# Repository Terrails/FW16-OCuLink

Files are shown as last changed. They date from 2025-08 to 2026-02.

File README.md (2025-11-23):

# OCuLink 8i Expansion Board for the Framework 16

## The schematic
rev1.1

The schematic in itself is pretty simple. You only need to connect the TX and RX PCIe lanes to the correct pins of the OCuLink connector. And then add components such as the EEPROM that the Embedded Controller (EC) on the laptop reads to configure GPIO pins and bifurcation.

A pdf version of the schematic is available [here](./imgs/schematic.pdf).

### EEPROM
As for the EEPROM, I have decided to use the same one that Framework is using in their [Dual SSD reference design](https://github.com/FrameworkComputer/ExpansionBay/tree/main/Dual%20SSD%20Reference%20Design). The `BR24G32FVT-3GE2`. The chip is marked as not recommended for new design according to Mouser, but it still seems to be in stock, although it can easily be swapped with another if required.

The EEPROM's address pins are all connected to the ground as that is the address the EC expects and by default the write protection (WP) is disabled by being connected to GND to allow writing data to it.

### Fans
For the fans I had to go with an alternative FPC header, as the one Framework uses on their boards was not available anywhere. The connector I use is slightly smaller, but still makes the connection nevertheless and the fans do spin up. I have specifically went with the [`AFC05-S04FIA-00`](https://www.lcsc.com/product-detail/C561383.html) that is available on LCSC to use with JLCPCB's assembly.

## Firmware
The firmware file is generated using [Framework's Expansion Bay tool](https://github.com/FrameworkComputer/ExpansionBayConfigurationGenerator). More info on the specific file I have been using in my testing and how I flashed it *SOON*.

## The PCB layout
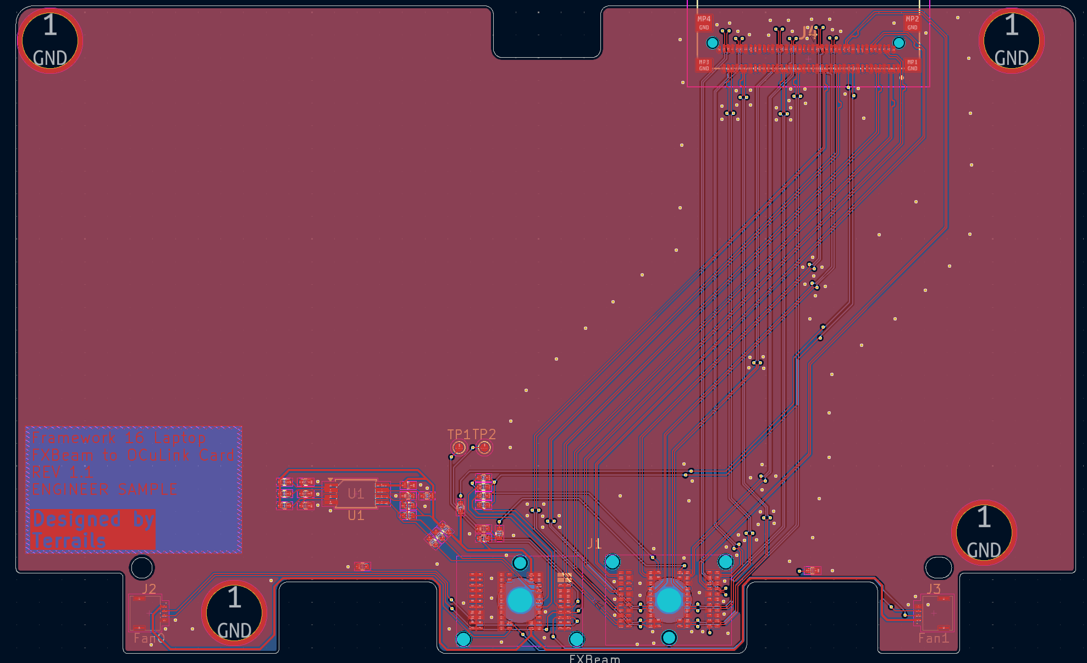
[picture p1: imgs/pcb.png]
rev1.1


For the layout I have went with a 4-layer board and did manage to successfully stay within JLCPCB's fabrication limits. For the production runs I have done a 1.2mm ENIG board and used the `Nan Ya NP-140F` material type with the `JLC04121H-1080` stackup and matched the differential pairs to it. I did also manage to stay within the minimum 0.3mm via hole size to keep costs somewhat down.

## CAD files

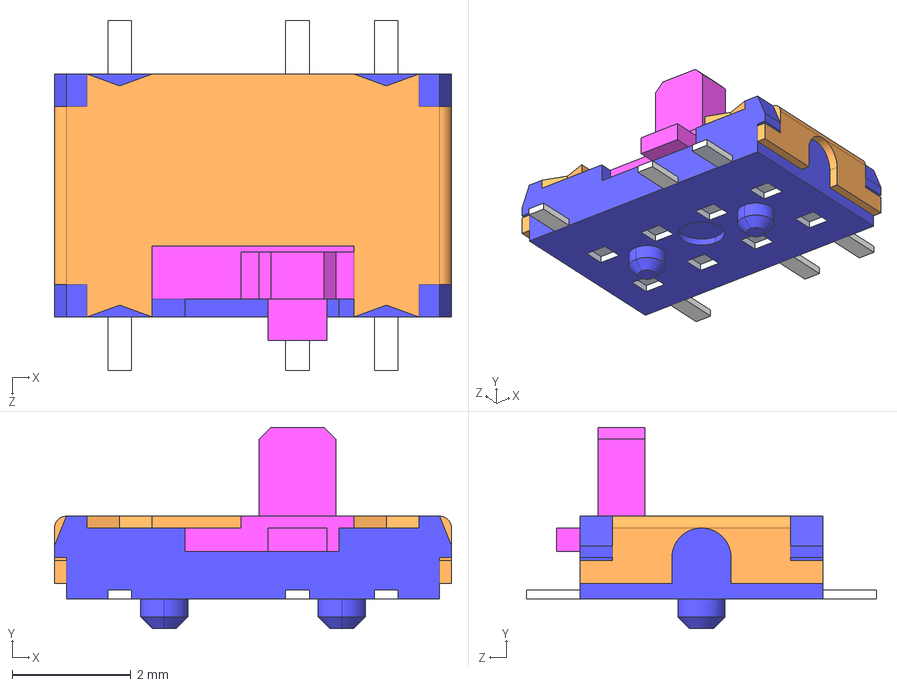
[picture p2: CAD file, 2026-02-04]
components/SSSS820101.stp
6.70 x 3.40 x 5.90 mm

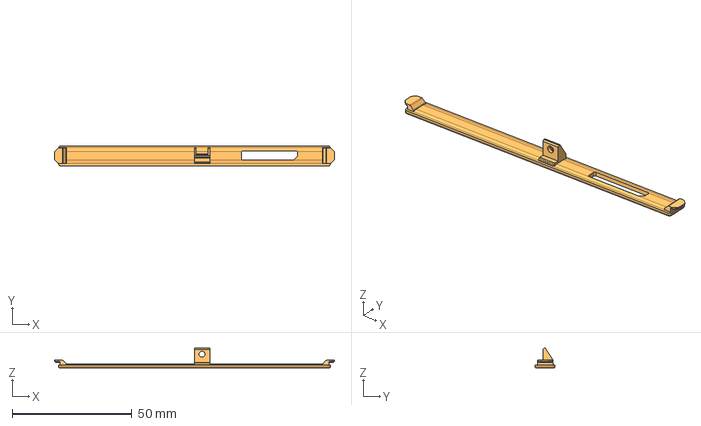
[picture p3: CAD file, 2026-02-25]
prints/IO-Shield.step
116.9 x 8.45 x 8.15 mm

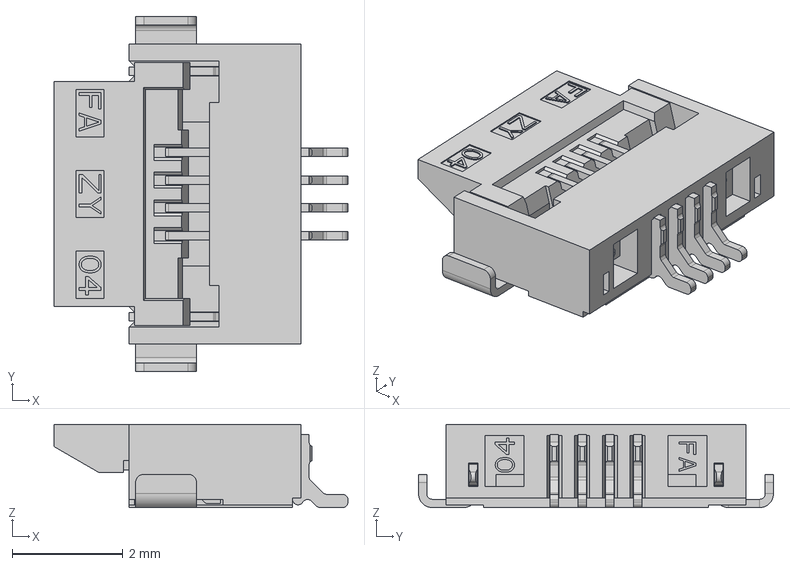
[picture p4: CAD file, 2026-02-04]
components/AFC58-S04FIA_4Pin.stp
5.30 x 6.40 x 1.50 mm

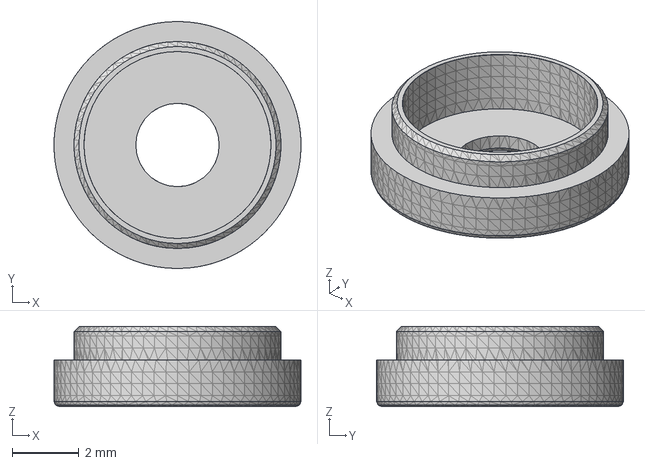
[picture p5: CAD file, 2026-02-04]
components/Expansion_Bay_Standoff.stp
7.40 x 7.40 x 2.40 mm

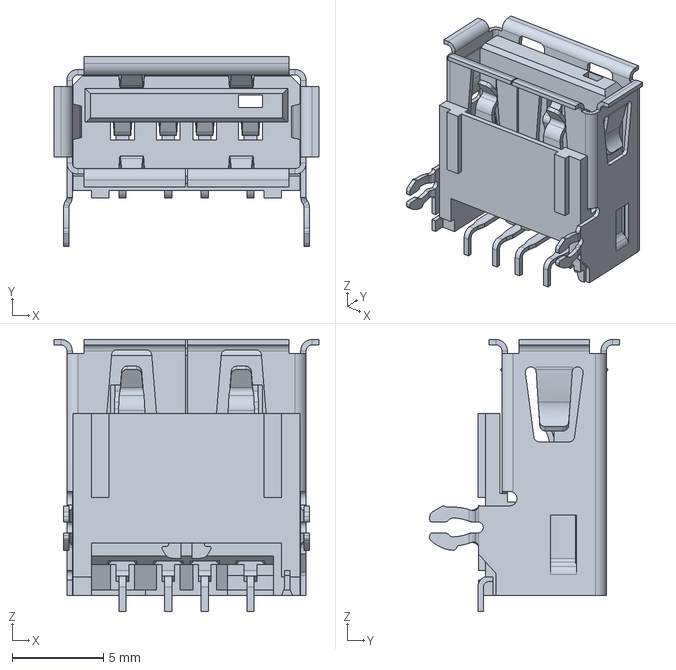
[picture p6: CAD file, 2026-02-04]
components/87583-2010BLF.stp
14.5 x 10.4 x 14.9 mm

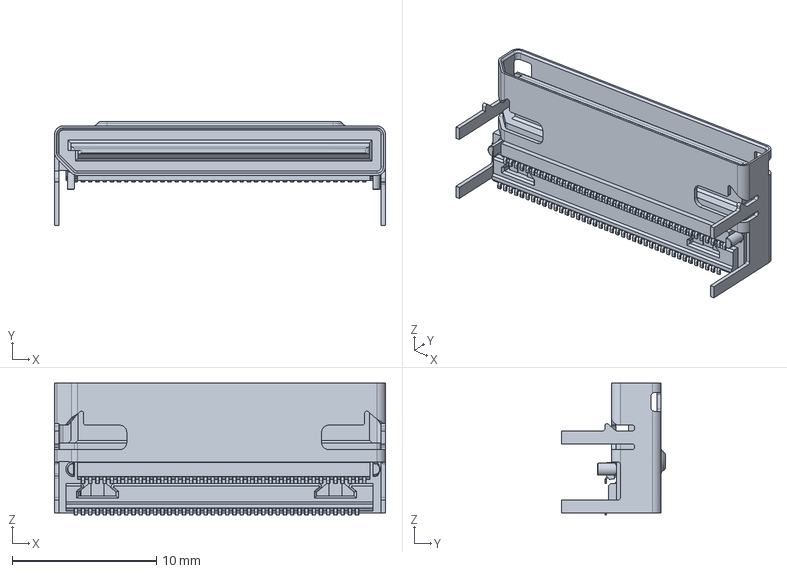
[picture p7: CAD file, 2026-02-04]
components/173162-0132.stp
22.9 x 7.21 x 9.14 mm

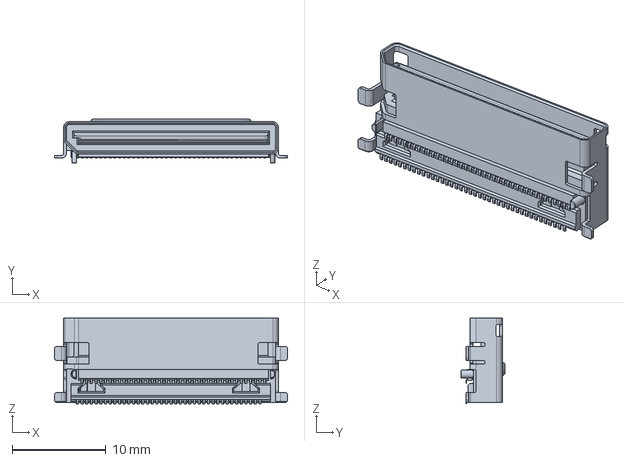
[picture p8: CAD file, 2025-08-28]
components/173162-0131.stp
24.9 x 4.72 x 9.14 mm

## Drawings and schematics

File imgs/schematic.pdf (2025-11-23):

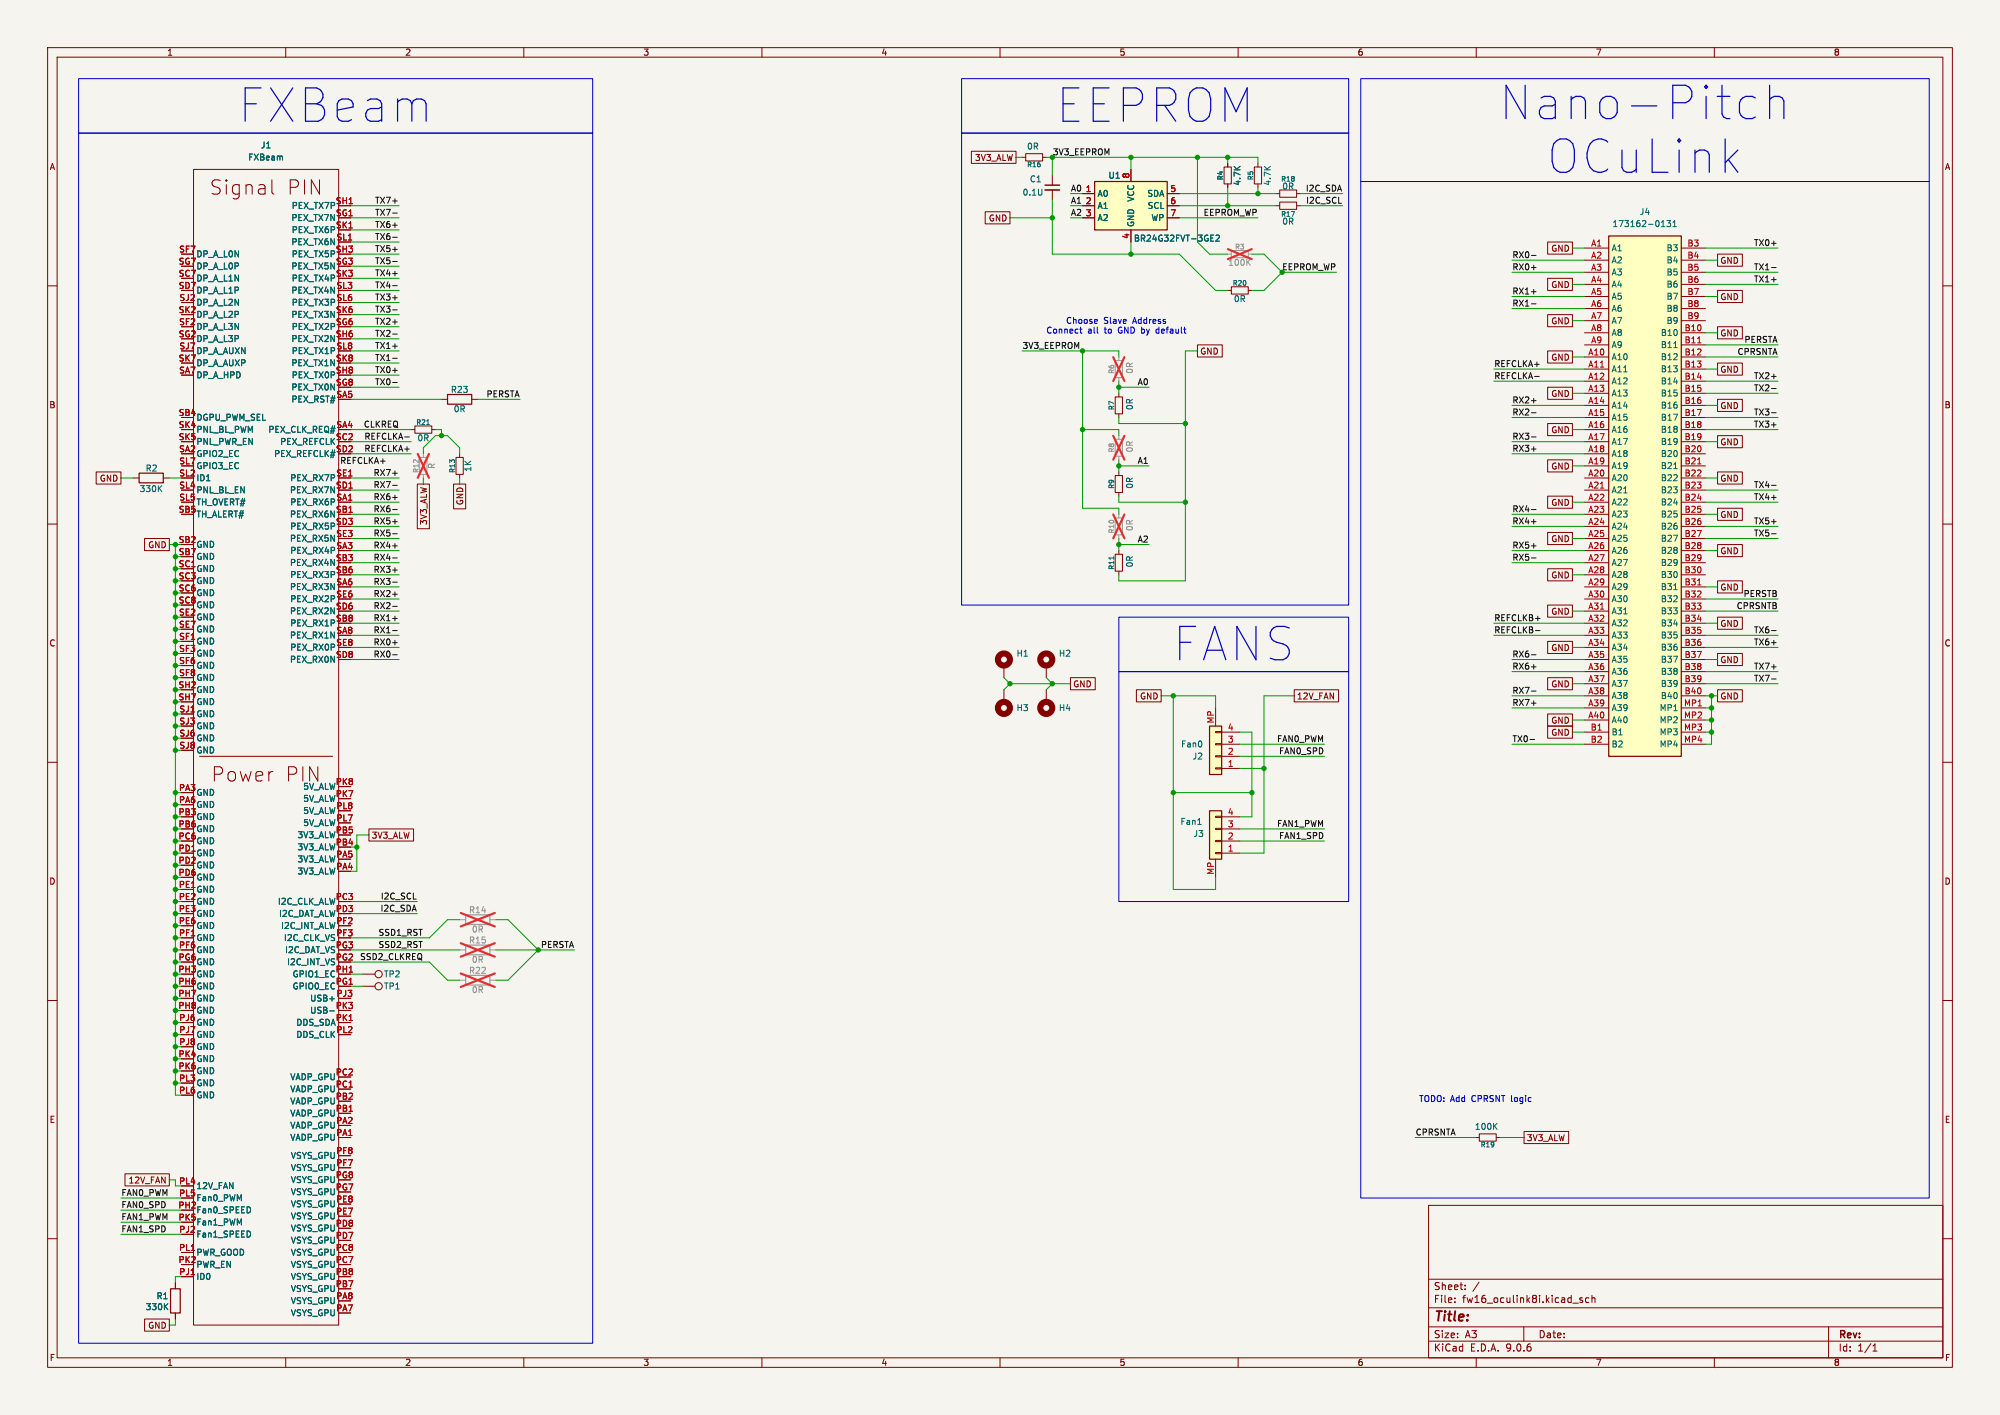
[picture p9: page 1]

Choose Slave Address Connect all to GND by default

ID1 SL2 PNL_BL_EN SL4 TH_OVERT# SL5 TH_ALERT# SB5 GND SB2 GND SB7 GND SC1 GND SC3 GND SC6 GND SC8 GND SE2 GND SE7 GND SF1 GND SF3 GND SF6 GND SF8 GND SH2 GND SH7 GND SJ1 GND SJ3 GND SJ6 GND SJ8 GND PA3 GND PA6 GND PB3 GND PB6 GND PC6 GND PD1 GND PD2 GND PD6 GND PE1 GND PE2 GND PE3 GND PE6 GND PF1 GND PF6 GND PG6GND PH3 GND PH6 GND PH7 GND PH8 GND PJ6 GND PJ7 GND PJ8 GND PK4 GND PK6 GND PL3 GND PL6

GND GND GND GND GND

Id: 1/1 Title: File: fw16_oculink8i.kicad_sch Sheet: /

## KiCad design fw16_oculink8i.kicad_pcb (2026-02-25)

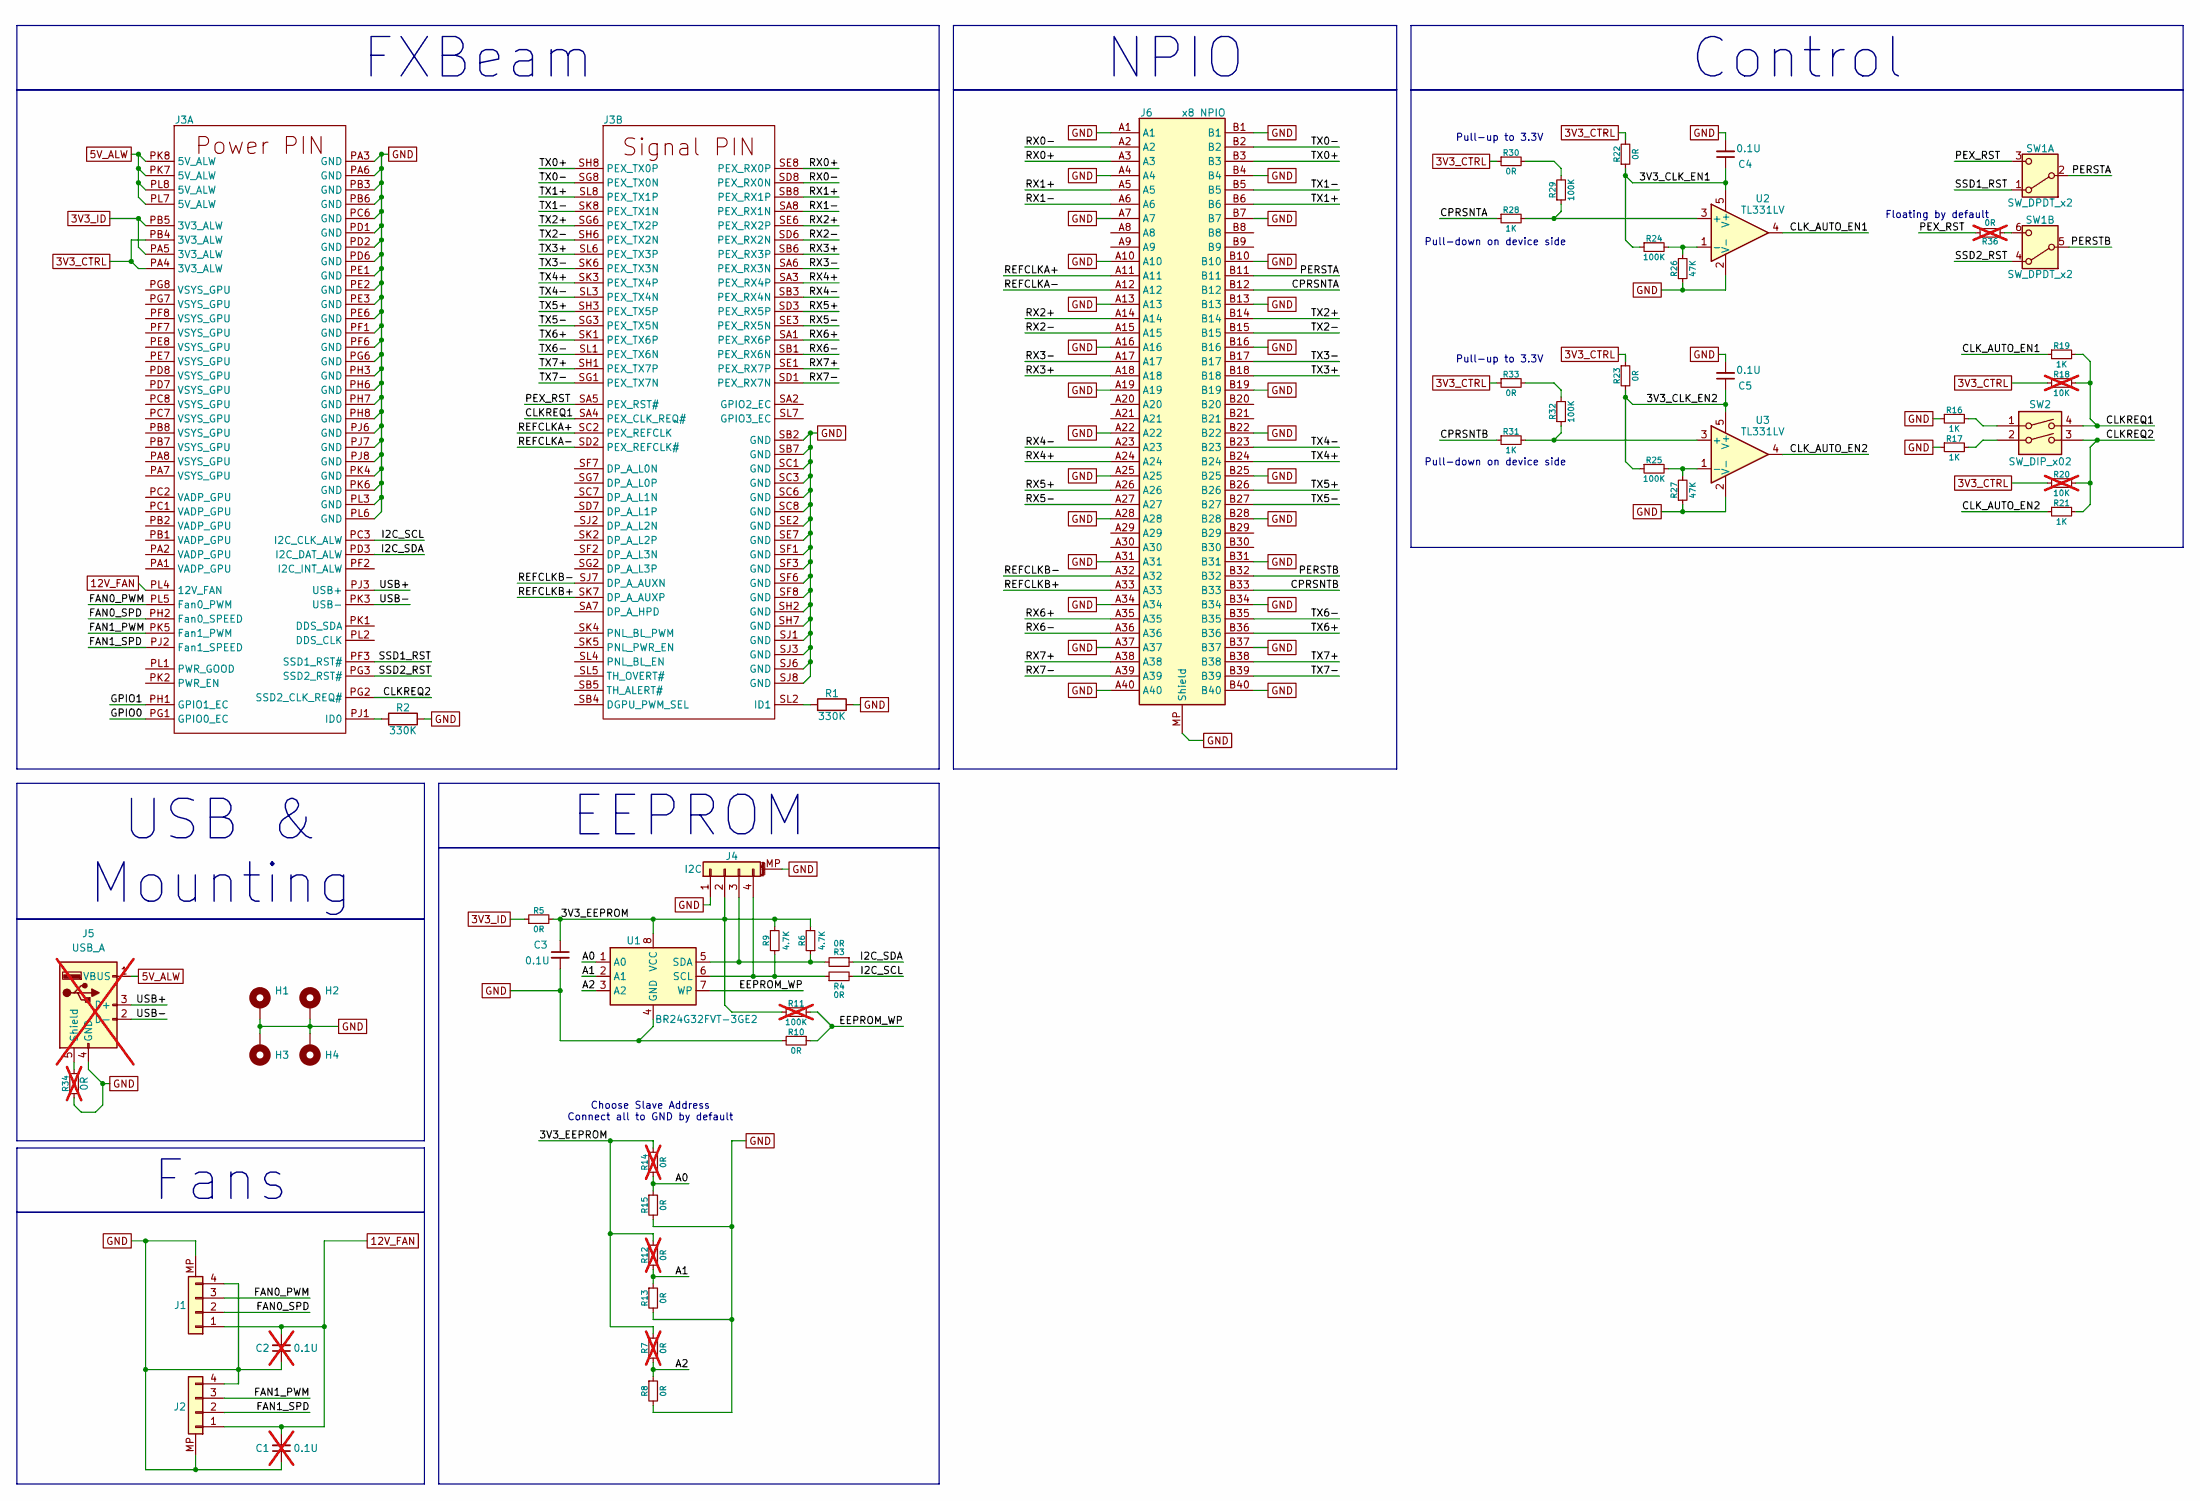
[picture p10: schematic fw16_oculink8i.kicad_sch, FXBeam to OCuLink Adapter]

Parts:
C1, C2: 0.1U; C_0402_1005Metric; not fitted
C3, C4, C5: 0.1U; C_0402_1005Metric
H1, H2, H3, H4: MountingHole_Pad; MountingHole_6.2mm_EasySolder_Cut
J1, J2: Fan; AFC58-S04FIA_4Pin; Part Nr. AFC58-S04FIA
J3: FXBeam
J4: I2C; JST_SH_SM04B-SRSS-TB_1x04-1MP_P1.00mm_Horizontal
J5: USB_A; 87583-2010BLF; not fitted
J6: x8 NPIO; Nano-Pitch-173162-0132
R1, R2: 330K; R_0402_1005Metric; Tolerance 1%
R3, R4, R5, R8, R10, R13, R15, R22, R23, R30, R33: 0R; R_0402_1005Metric
R6, R9: 4.7K; R_0402_1005Metric; Tolerance 1%
R7, R12, R14, R34, R36: 0R; R_0402_1005Metric; not fitted
R11: 100K; R_0402_1005Metric; Tolerance 1%; not fitted
R16, R17, R19, R21, R28, R31: 1K; R_0402_1005Metric
R18, R20: 10K; R_0402_1005Metric; not fitted
R24, R25, R29, R32: 100K; R_0402_1005Metric
R26, R27: 47K; R_0402_1005Metric
SW1: SW_DPDT_x2; SSSS820101
SW2: SW_DIP_x02; SW_DIP_SPSTx02_Slide_Copal_CHS-02B_W7.62mm_P1.27mm
U1: BR24G32FVT-3GE2; TSSOP-8_4.4x3mm_P0.65mm
U2, U3: TL331LV; SOT-23-5

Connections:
3V3_CTRL: J3.PA4 (3V3_ALW), J3.PB4 (3V3_ALW), R18.1, R20.1, R22.2, R23.1, R30.1, R33.1
3V3_ID: J3.PA5 (3V3_ALW), J3.PB5 (3V3_ALW), R5.1
5V_ALW: J3.PK7 (5V_ALW), J3.PK8 (5V_ALW), J3.PL7 (5V_ALW), J3.PL8 (5V_ALW), J5.1 (VBUS)
12V_FAN: C1.2, C2.2, J1.1, J2.1, J3.PL4 (12V_FAN)
/3V3_CLK_EN1: C4.1, R22.1, R24.1, U2.5 (V+)
/3V3_CLK_EN2: C5.1, R23.2, R25.1, U3.5 (V+)
/3V3_EEPROM: C3.1, J4.2, R5.2, R6.2, R7.1, R9.1, R11.2, R12.1, R14.1, U1.8 (VCC)
/A0: R14.2, R15.1, U1.1 (A0)
/A1: R12.2, R13.1, U1.2 (A1)
/A2: R7.2, R8.1, U1.3 (A2)
/CLKREQ1: J3.SA4 (PEX_CLK_REQ#), R18.2, R19.2, SW2.4
/CLKREQ2: J3.PG2 (SSD2_CLK_REQ#), R20.2, R21.2, SW2.3
/CLK_AUTO_EN1: R19.1, U2.4
/CLK_AUTO_EN2: R21.1, U3.4
/CPRSNTA: J6.B12, R28.1
/CPRSNTB: J6.B33, R31.1
/EEPROM_WP: R10.1, R11.1, U1.7 (WP)
/FAN0_PWM: J1.3, J3.PL5 (Fan0_PWM)
/FAN0_SPD: J1.2, J3.PH2 (Fan0_SPEED)
/FAN1_PWM: J2.3, J3.PK5 (Fan1_PWM)
/FAN1_SPD: J2.2, J3.PJ2 (Fan1_SPEED)
/GPIO0: J3.PG1 (GPIO0_EC)
/GPIO1: J3.PH1 (GPIO1_EC)
/I2C_SCL: J3.PC3 (I2C_CLK_ALW), R4.2
/I2C_SDA: J3.PD3 (I2C_DAT_ALW), R3.1
/PERSTA: J6.B11, SW1.2 (B)
/PERSTB: J6.B32, SW1.5 (B)
/PEX_RST: J3.SA5 (PEX_RST#), R36.2, SW1.3 (C)
/REFCLKA+: J3.SC2 (PEX_REFCLK), J6.A11
/REFCLKA-: J3.SD2 (PEX_REFCLK#), J6.A12
/REFCLKB+: J3.SK7 (DP_A_AUXP), J6.A33
/REFCLKB-: J3.SJ7 (DP_A_AUXN), J6.A32
/RX0+: J3.SE8 (PEX_RX0P), J6.A3
/RX0-: J3.SD8 (PEX_RX0N), J6.A2
/RX1+: J3.SB8 (PEX_RX1P), J6.A5
/RX1-: J3.SA8 (PEX_RX1N), J6.A6
/RX2+: J3.SE6 (PEX_RX2P), J6.A14
/RX2-: J3.SD6 (PEX_RX2N), J6.A15
/RX3+: J3.SB6 (PEX_RX3P), J6.A18
/RX3-: J3.SA6 (PEX_RX3N), J6.A17
/RX4+: J3.SA3 (PEX_RX4P), J6.A24
/RX4-: J3.SB3 (PEX_RX4N), J6.A23
/RX5+: J3.SD3 (PEX_RX5P), J6.A26
/RX5-: J3.SE3 (PEX_RX5N), J6.A27
/RX6+: J3.SA1 (PEX_RX6P), J6.A35
/RX6-: J3.SB1 (PEX_RX6N), J6.A36
/RX7+: J3.SE1 (PEX_RX7P), J6.A38
/RX7-: J3.SD1 (PEX_RX7N), J6.A39
/SSD1_RST: J3.PF3 (SSD1_RST#), SW1.1 (A)
/SSD2_RST: J3.PG3 (SSD2_RST#), SW1.4 (A)
/TX0+: J3.SH8 (PEX_TX0P), J6.B3
/TX0-: J3.SG8 (PEX_TX0N), J6.B2
/TX1+: J3.SL8 (PEX_TX1P), J6.B6
/TX1-: J3.SK8 (PEX_TX1N), J6.B5
/TX2+: J3.SG6 (PEX_TX2P), J6.B14
/TX2-: J3.SH6 (PEX_TX2N), J6.B15
/TX3+: J3.SL6 (PEX_TX3P), J6.B18
/TX3-: J3.SK6 (PEX_TX3N), J6.B17
/TX4+: J3.SK3 (PEX_TX4P), J6.B24
/TX4-: J3.SL3 (PEX_TX4N), J6.B23
/TX5+: J3.SH3 (PEX_TX5P), J6.B26
/TX5-: J3.SG3 (PEX_TX5N), J6.B27
/TX6+: J3.SK1 (PEX_TX6P), J6.B36
/TX6-: J3.SL1 (PEX_TX6N), J6.B35
/TX7+: J3.SH1 (PEX_TX7P), J6.B38
/TX7-: J3.SG1 (PEX_TX7N), J6.B39
/USB+: J3.PJ3 (USB+), J5.3 (D+)
/USB-: J3.PK3 (USB-), J5.2 (D-)
GND: C1.1, C2.1, C3.2, C4.2, C5.2, H1.1, H2.1, H3.1, H4.1, J1.4, J1.MP, J2.4, J2.MP, J3.PA3 (GND), J3.PA6 (GND), J3.PB3 (GND), J3.PB6 (GND), J3.PC6 (GND), J3.PD1 (GND), J3.PD2 (GND), J3.PD6 (GND), J3.PE1 (GND), J3.PE2 (GND), J3.PE3 (GND), J3.PE6 (GND), J3.PF1 (GND), J3.PF6 (GND), J3.PG6 (GND), J3.PH3 (GND), J3.PH6 (GND), J3.PH7 (GND), J3.PH8 (GND), J3.PJ6 (GND), J3.PJ7 (GND), J3.PJ8 (GND), J3.PK4 (GND), J3.PK6 (GND), J3.PL3 (GND), J3.PL6 (GND), J3.SB2 (GND), J3.SB7 (GND), J3.SC1 (GND), J3.SC3 (GND), J3.SC6 (GND), J3.SC8 (GND), J3.SE2 (GND), J3.SE7 (GND), J3.SF1 (GND), J3.SF3 (GND), J3.SF6 (GND), J3.SF8 (GND), J3.SH2 (GND), J3.SH7 (GND), J3.SJ1 (GND), J3.SJ3 (GND), J3.SJ6 (GND), J3.SJ8 (GND), J4.1, J4.MP (MountPin), J5.4 (GND), J6.A1, J6.A4, J6.A7, J6.A10, J6.A13, J6.A16, J6.A19, J6.A22, J6.A25, J6.A28, J6.A31, J6.A34, J6.A37, J6.A40, J6.B1, J6.B4, J6.B7, J6.B10, J6.B13, J6.B16, J6.B19, J6.B22, J6.B25, J6.B28, J6.B31, J6.B34, J6.B37, J6.B40, J6.MP (Shield), R1.1, R2.1, R8.2, R10.2, R13.2, R15.2, R16.1, R17.1, R26.1, R27.1, R34.2, U1.4 (GND), U2.2 (V-), U3.2 (V-)
unnamed: J3.PJ1 (ID0), R2.2
unnamed: J3.SL2 (ID1), R1.2
unnamed: J4.3, R3.2, R6.1, U1.5 (SDA)
unnamed: J4.4, R4.1, R9.2, U1.6 (SCL)
unnamed: J5.5 (Shield), R34.1
unnamed: R16.2, SW2.1
unnamed: R17.2, SW2.2
unnamed: R29.2, R30.2
unnamed: R32.2, R33.2
unnamed: R36.1, SW1.6 (C)
unnamed: R28.2, R29.1, U2.3 (+)
unnamed: R24.2, R26.2, U2.1 (-)
unnamed: R31.2, R32.1, U3.3 (+)
unnamed: R25.2, R27.2, U3.1 (-)

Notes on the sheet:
Pull-down on device side
Pull-up to 3.3V
Choose Slave Address Connect all to GND by default
Floating by default
Pull-down on device side
EEPROM
Fans
NPIO
FXBeam
USB & Mounting
Control

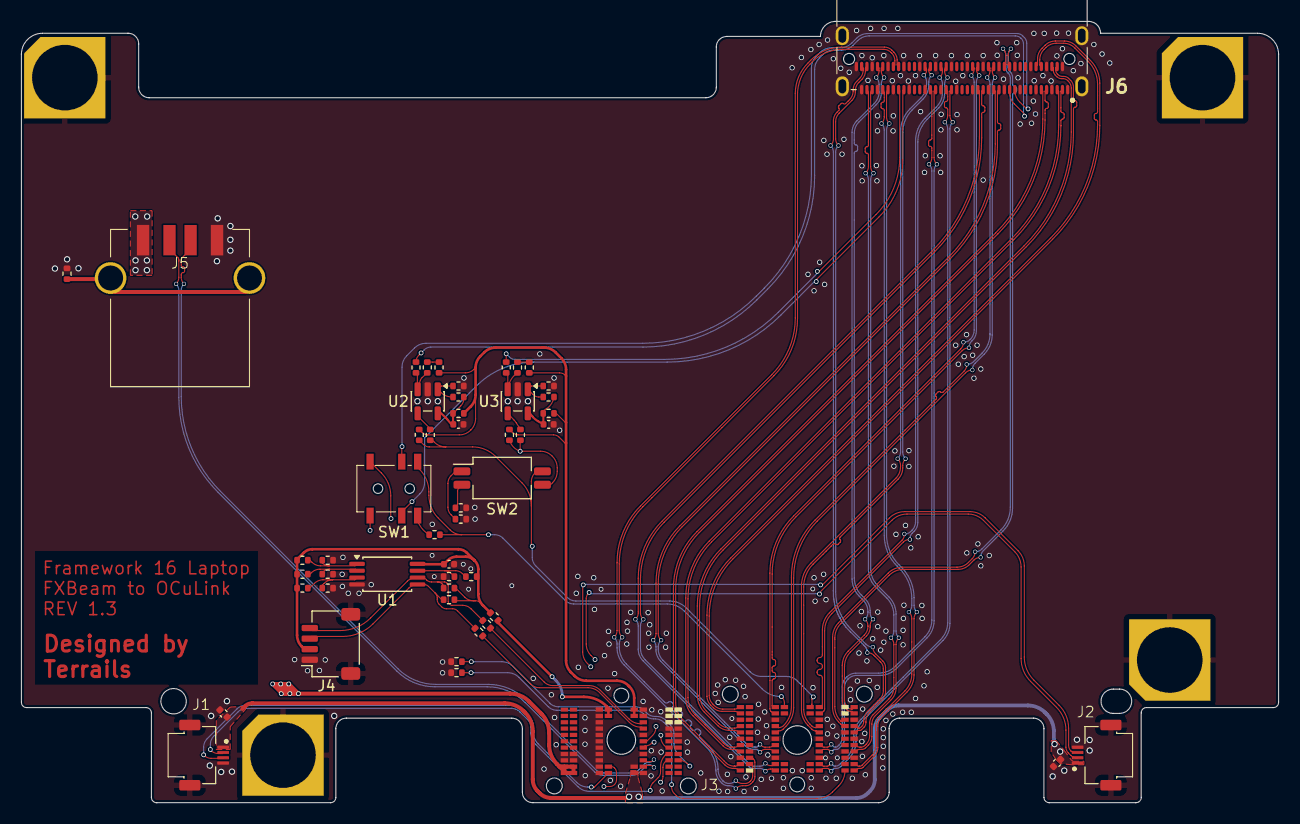
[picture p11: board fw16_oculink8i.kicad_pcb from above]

Board: 4 copper layers, 119.0 x 73.9 mm, 55 parts (0 on the bottom side), 81 nets.

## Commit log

2025-08-28 resize page to a3 and add 3d model to nano-pitch connector
    [fw16_oculink8i.kicad_pcb]
2025-08-28 improve: remove unnecessary circles and cleanup DRC
    [fw16_oculink8i.kicad_pcb]
2025-08-28 Switch to 0R resistor rather than jumper solder pads
    [fw16_oculink8i.kicad_pcb, fw16_oculink8i.kicad_sch]
2025-08-28 Change resistor numbering
    [fw16_oculink8i.kicad_pcb, fw16_oculink8i.kicad_sch]
2025-08-28 schematic cleanup
    [fw16_oculink8i.kicad_pcb, fw16_oculink8i.kicad_sch]
2025-08-28 Add datasheets to parts
    [fw16_oculink8i.kicad_sch]
2025-08-28 Remove FXBeam from BOM
    [fw16_oculink8i.kicad_pcb, fw16_oculink8i.kicad_sch]
2025-08-28 Add R0 resistors to EEPROM power supply
    [fw16_oculink8i.kicad_pcb, fw16_oculink8i.kicad_sch]
2025-08-28 Configure board physical stackup
    [fw16_oculink8i.kicad_pcb]
2025-08-28 Configure board finish to ENIG
    [fw16_oculink8i.kicad_pcb]
2025-08-29 Add R0 resistor to CPRSNT oculink pin
    [fw16_oculink8i.kicad_pcb, fw16_oculink8i.kicad_sch]
2025-09-13 Remove unnecessary resistors from BOM
    [fw16_oculink8i.kicad_pcb, fw16_oculink8i.kicad_sch]
2025-09-15 Create separate nano-pitch footprint with JLC DRC rules
    [1731620131.stp, fw16_oculink8i.kicad_pcb, fw16_oculink8i.kicad_sch]
2025-09-15 Remove unnecessary vias
    [fw16_oculink8i.kicad_pcb]
2025-11-15 Add CLKREQ trace and GND EEPROM WP resistor
    [fw16_oculink8i.kicad_pcb, fw16_oculink8i.kicad_sch]
2025-11-15 Update to rev 1.1 due to CLKREQ and EEPROM WP updates
    [fw16_oculink8i.kicad_pcb]
2025-11-15 Update fill zones
    [fw16_oculink8i.kicad_pcb]
2025-11-15 Update pcb image with new rev
2025-11-16 Finalize rev 1.1
    [fw16_oculink8i.kicad_pcb, fw16_oculink8i.kicad_sch]
2025-11-16 Fix pair skews
    [fw16_oculink8i.kicad_pcb]
2025-11-16 Final cleanup
    [fw16_oculink8i.kicad_pcb]
2025-11-23 update schematic and pcb imgs
2025-11-23 update board production details
2025-12-28 working rev1.1
    [fw16_oculink8i.kicad_pcb, fw16_oculink8i.kicad_sch]
2026-01-20 add IO-Shield step file
    [IO-Shield.step]
2026-02-04 finalized rev1.2 order
    [173162-0131.stp, 173162-0132.stp, 87583-2010BLF.stp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]
2026-02-22 finalize rev1.3
    [fw16_oculink8i.kicad_pcb, fw16_oculink8i.kicad_sch]
2026-02-25 finalize rev1.3 for real now... maybe
    [fw16_oculink8i.kicad_pcb, fw16_oculink8i.kicad_sch]
